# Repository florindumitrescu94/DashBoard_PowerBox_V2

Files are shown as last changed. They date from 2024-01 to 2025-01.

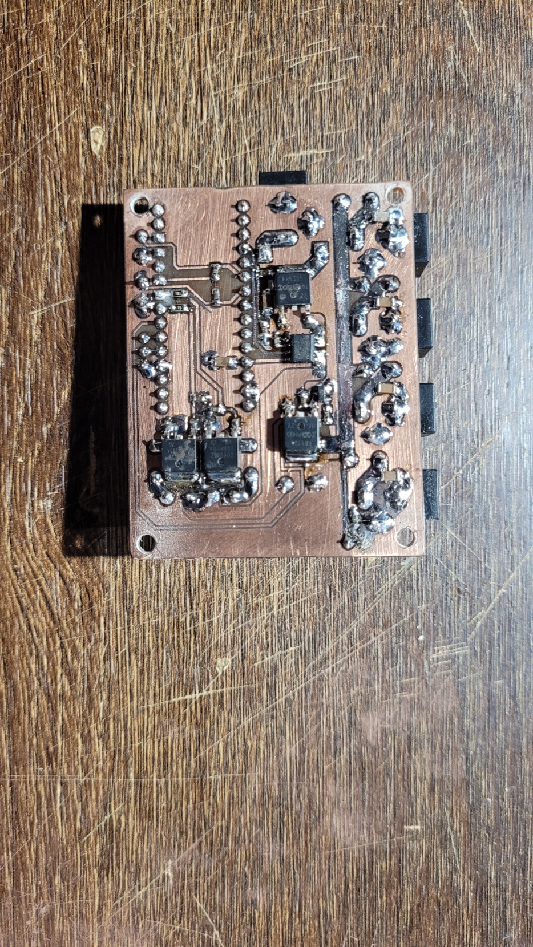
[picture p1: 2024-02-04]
DashBoard_PowerBox_V2_Documents/pcb_after_components_bottom.jpg

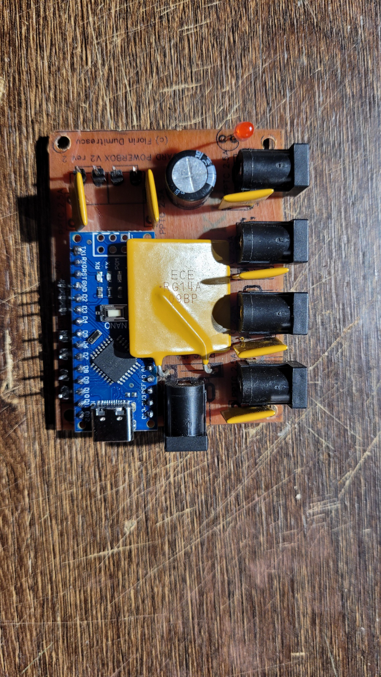
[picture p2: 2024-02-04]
DashBoard_PowerBox_V2_Documents/pcb_after_components_top.jpg

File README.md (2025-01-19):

# DashBoard PowerBoxV2
<p>Improved DIY powerbox based on Arduino Nano, with environmental sensors, power condition monitoring and dew heater power automation based on temperature probes</p>
<p>Please see <a href="https://github.com/florindumitrescu94/DashBoard_PowerBox_V2/wiki"> Wiki page </a> for more information.</p>
</br>
<p>To report any issues or request new features, please use the <a href=https://github.com/florindumitrescu94/DashBoard_PowerBox_V2/issues>Issues page</a></p>
</br>
<p>All feedback and suggestions are welcome! You can use the <a href=https://github.com/florindumitrescu94/DashBoard_PowerBox_V2/discussions> Discussions page</a> to share your ideas, ask questions or get help. </p>

</br>
</br>
</br>
</br>
</br>
<p>For direct contact, you can reach me at florin.dumitrescu94@gmail.com </p>
<p>Special thanks to wittinobi for making his driver code available! I have learned how an ASCOM driver works by analyzing his code.</p>

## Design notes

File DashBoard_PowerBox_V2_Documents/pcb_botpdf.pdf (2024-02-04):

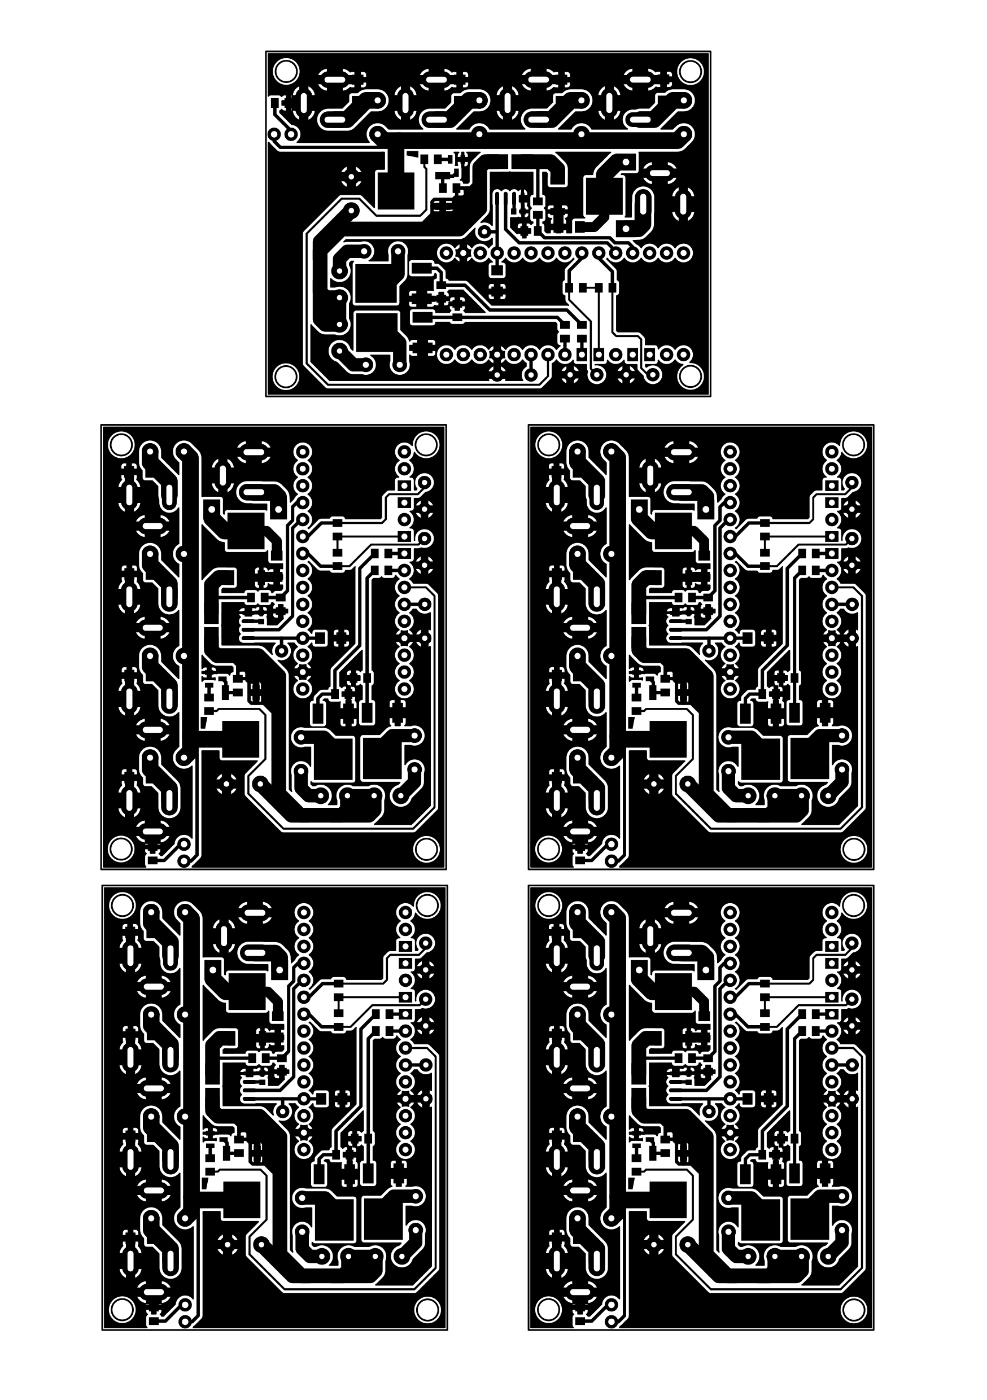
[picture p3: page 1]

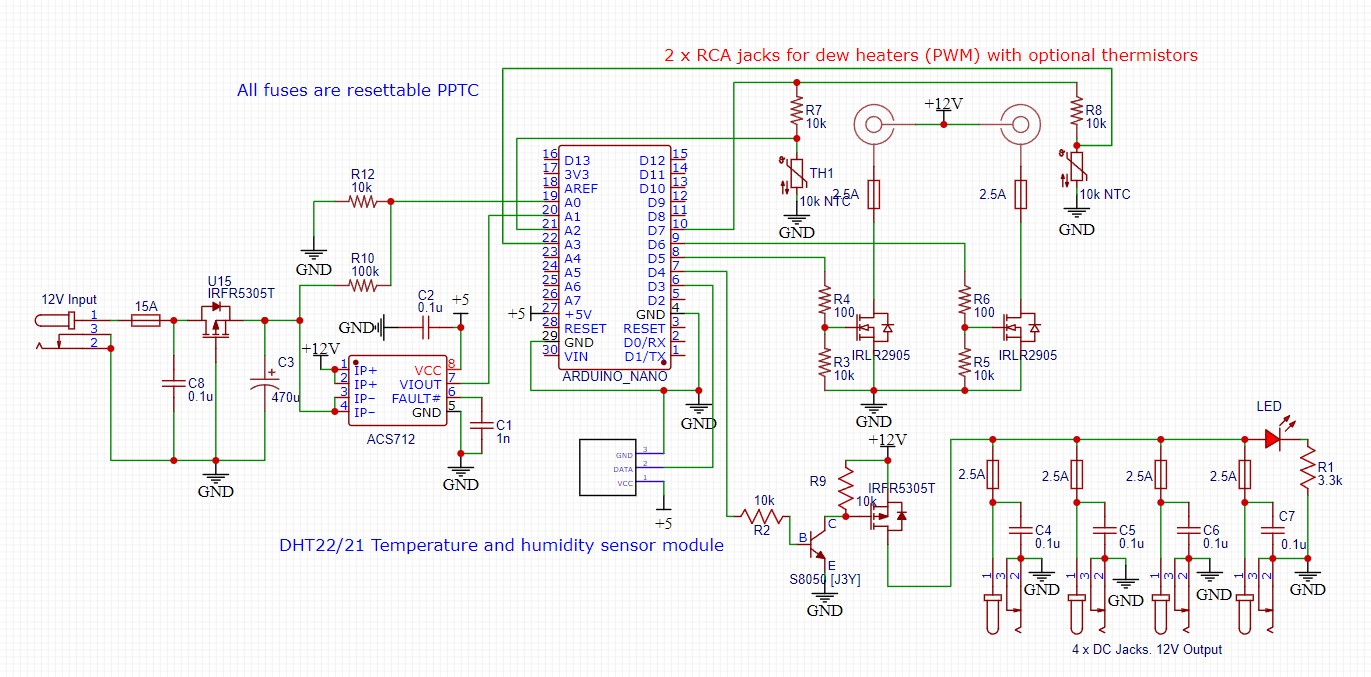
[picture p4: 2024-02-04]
DashBoard_PowerBox_V2_Documents/Schematic.jpg

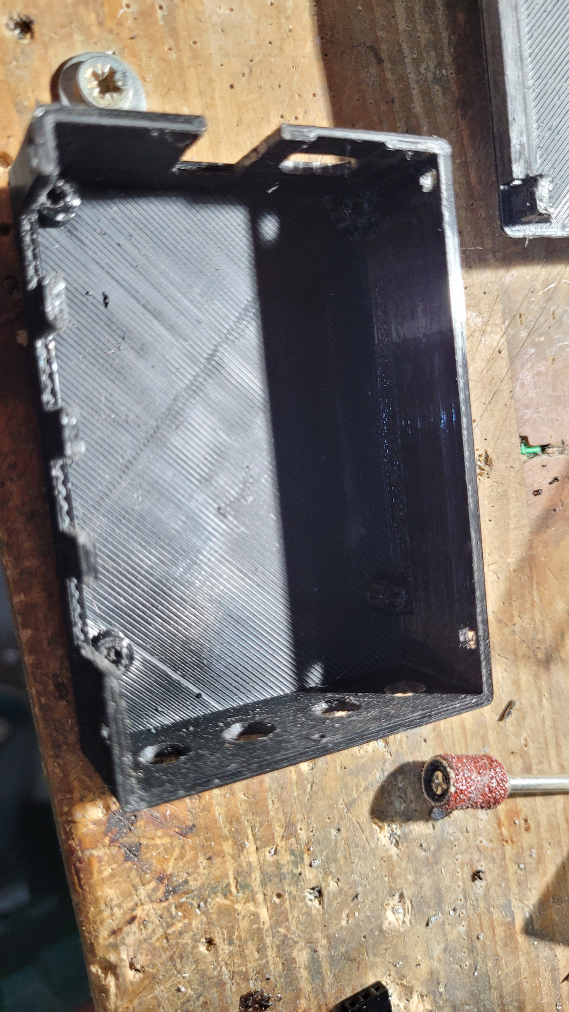
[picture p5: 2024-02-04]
DashBoard_PowerBox_V2_Documents/dashboard_inside_box.jpg

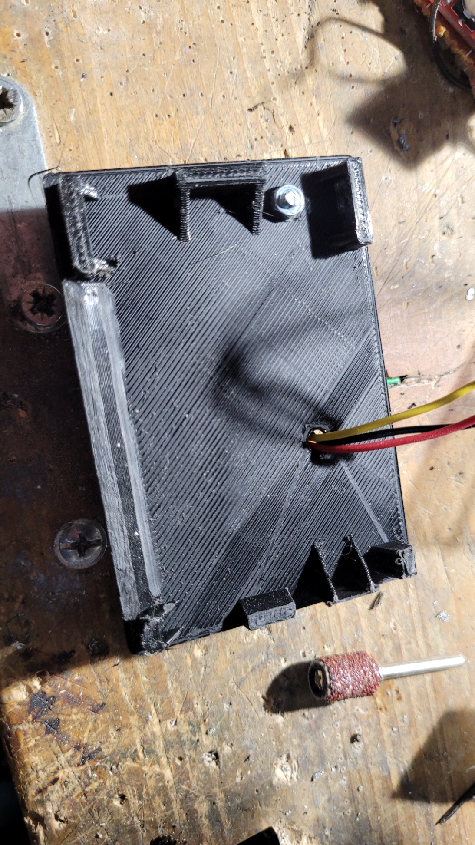
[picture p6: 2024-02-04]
DashBoard_PowerBox_V2_Documents/dashboard_inside_lid.jpg

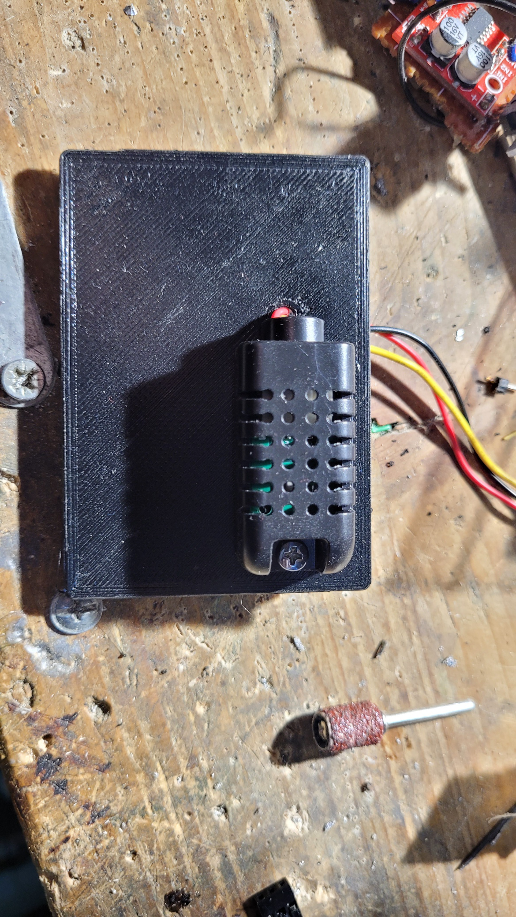
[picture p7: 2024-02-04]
DashBoard_PowerBox_V2_Documents/dashboard_lid_dhtsensor.jpg

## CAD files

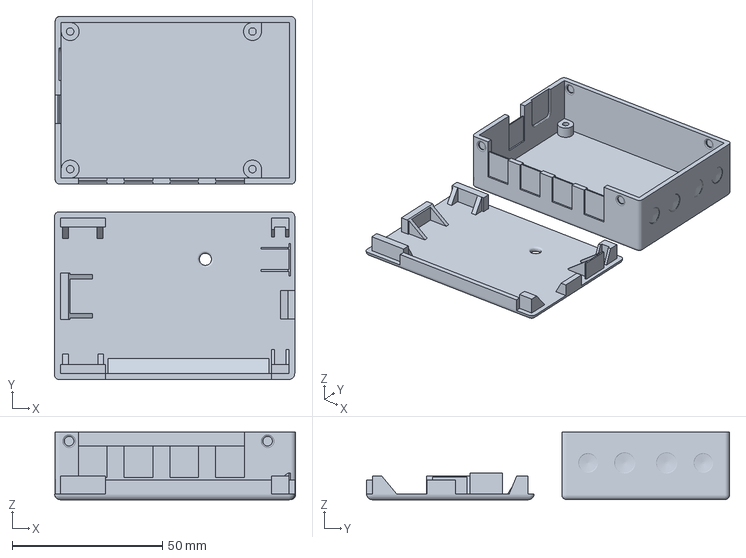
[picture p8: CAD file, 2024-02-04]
DashBoard_PowerBox_V2_Documents/CE3E3V2_DashBoard_PowerBox_V2 v2.3mf
80.2 x 120.8 x 22.5 mm

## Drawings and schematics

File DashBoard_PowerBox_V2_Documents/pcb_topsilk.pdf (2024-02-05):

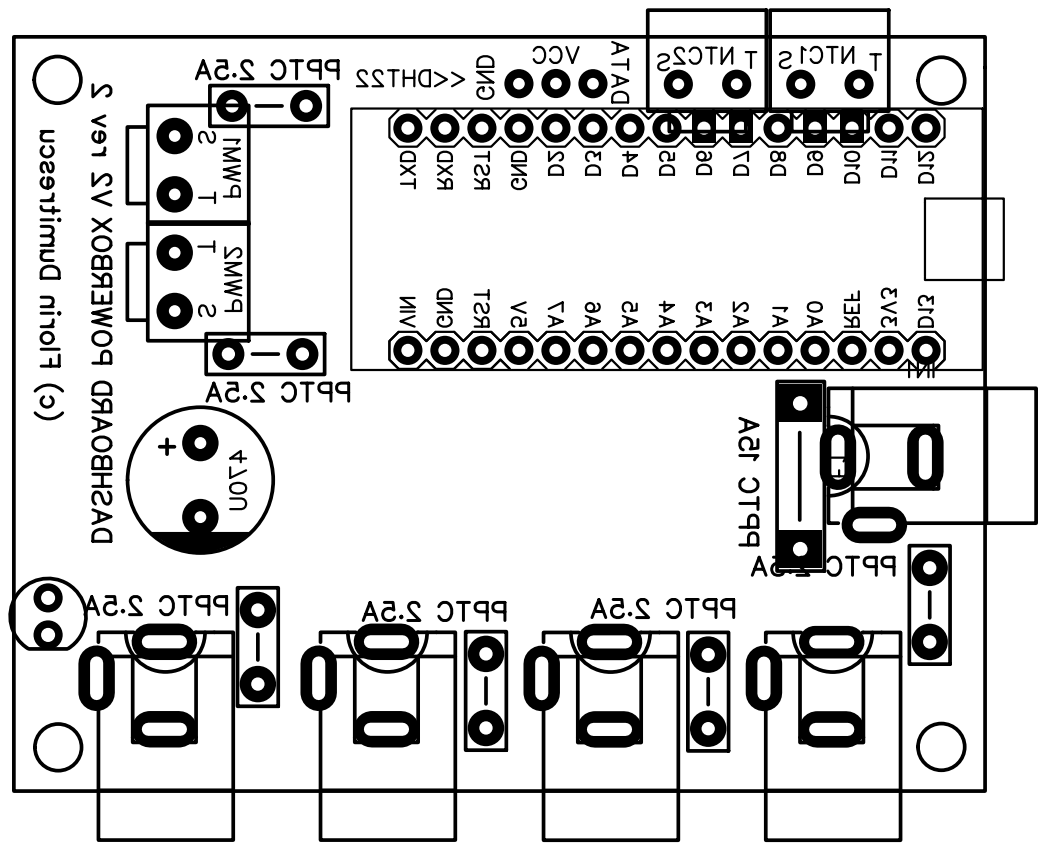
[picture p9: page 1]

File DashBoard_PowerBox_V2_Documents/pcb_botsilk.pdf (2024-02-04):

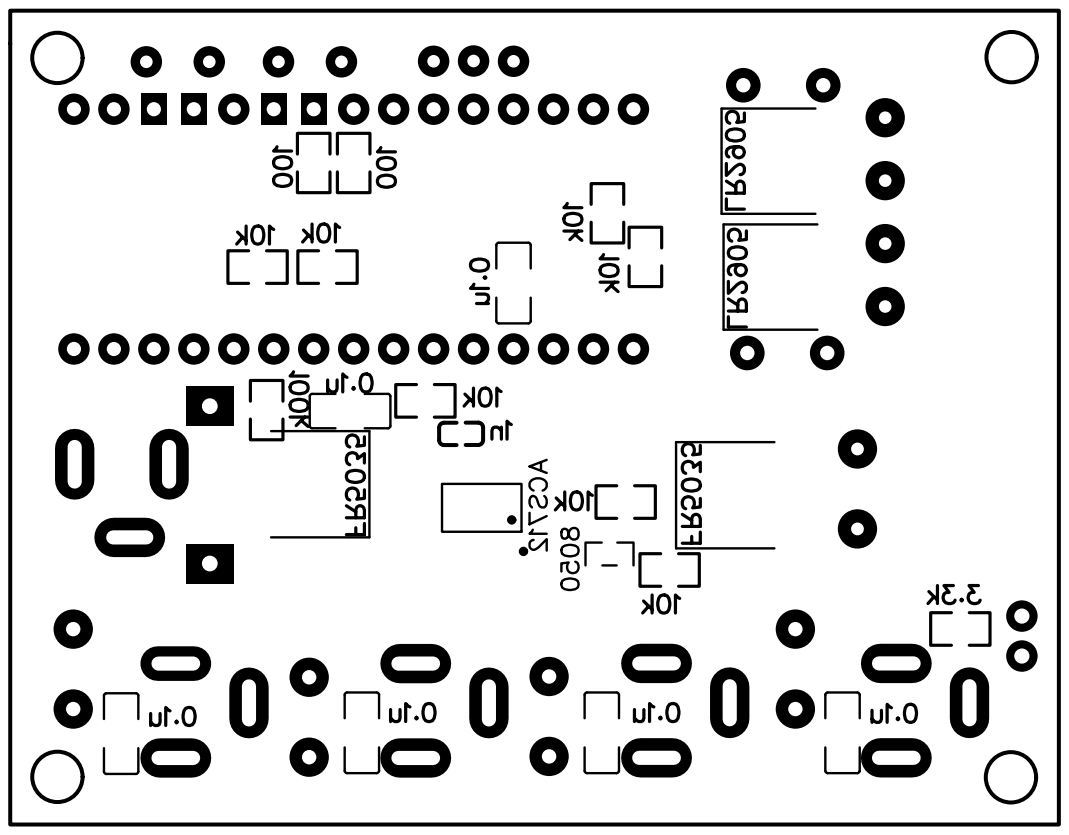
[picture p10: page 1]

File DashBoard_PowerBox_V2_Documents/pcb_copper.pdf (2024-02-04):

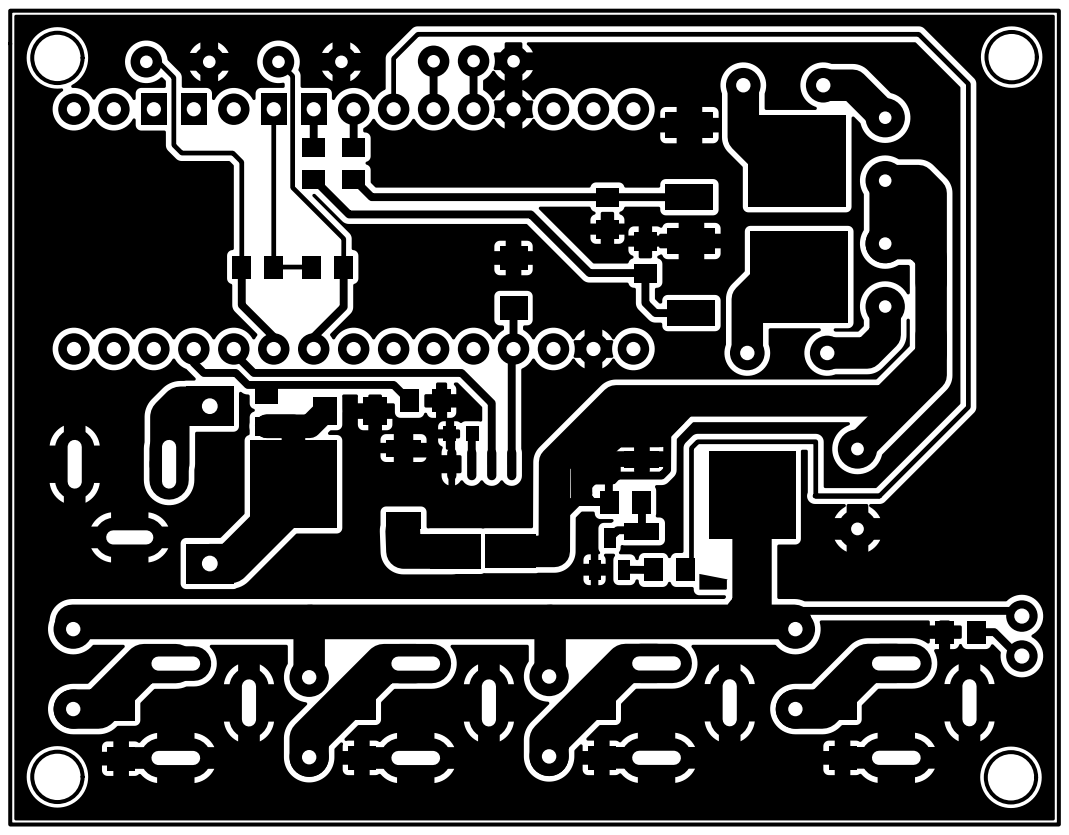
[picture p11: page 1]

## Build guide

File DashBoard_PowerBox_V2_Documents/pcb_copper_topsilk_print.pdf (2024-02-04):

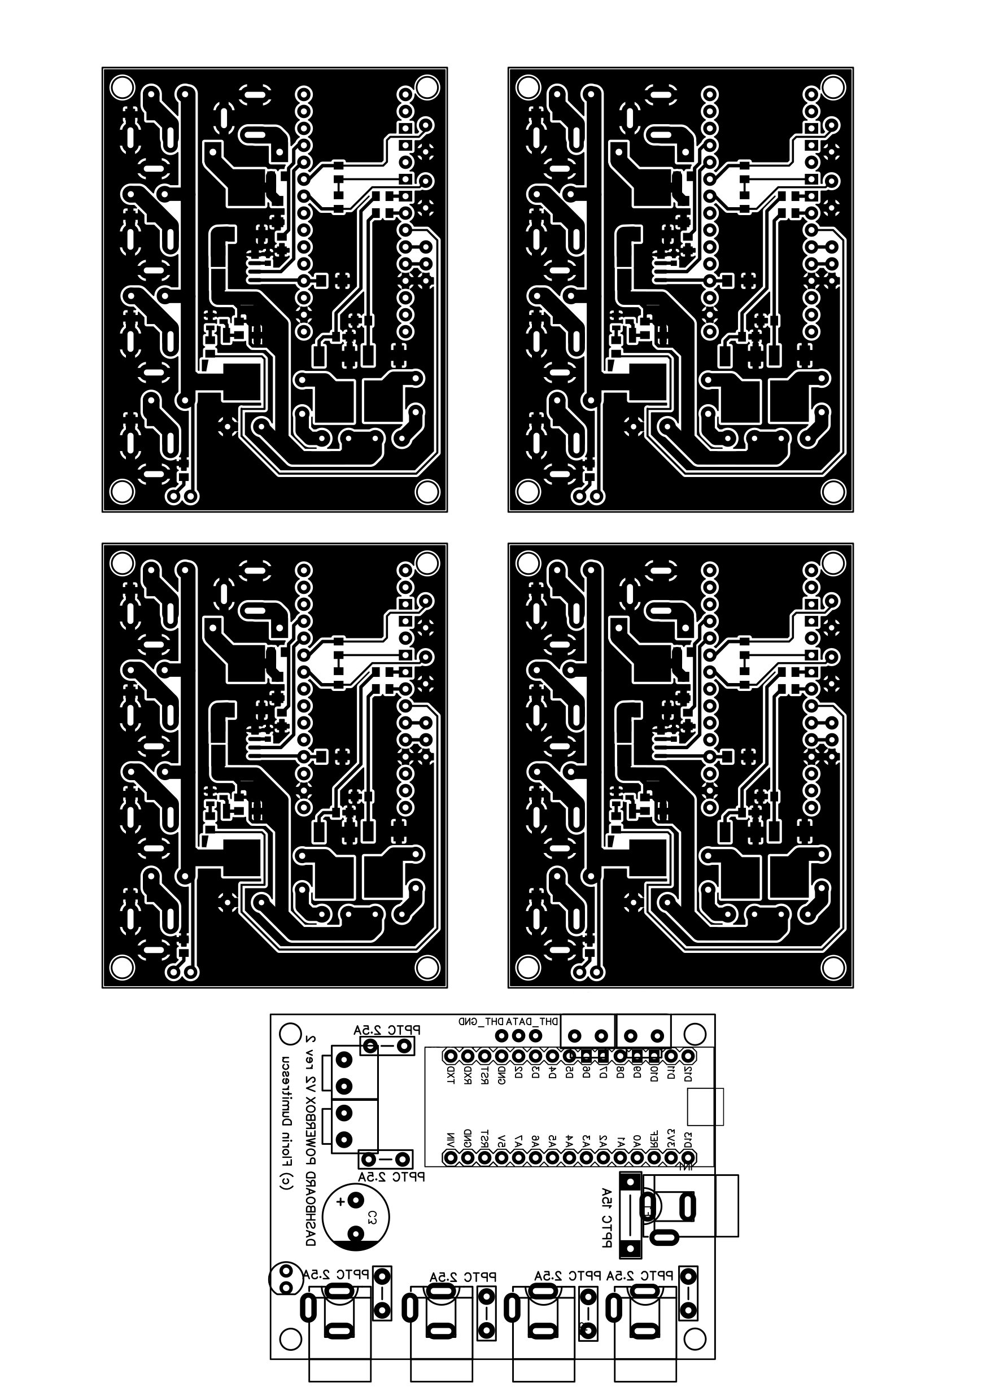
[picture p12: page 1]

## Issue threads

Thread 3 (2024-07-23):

No separators displayed

energiebrand, 2024-07-23:
I have the problem that under N.I.N.A. (ASCOM) unfortunately no separators are displayed in the measured values. For example, if the temperature is 23.45°C, then in N.I.N.A "2345" will be displayed. Could this be due to the ASCOM driver? Here in Germany (possibly all of Europe) a comma is expected as a separator, not a period. Is this where the problem lies?

florindumitrescu94, 2024-07-23:
Hello! It could be that.. I am in Europe too, but I've always been using US
settings on my computer, so I've never faced this issue.

Thing is, there is no setting in the ASCOM driver that I know of that sets
the decimal separator. Also, the values in the arduino also have a dot as a
decimal separator.

I tried changing my settings to use a comma as a decimal separator, but
NINA seems to be using a dot as a decimal separator, anyways, so I suspect
it is forcing the decimal separator to always be "." in its' code. When I
tried starting the powerbox driver with the Region settings set to Germany,
I got the same result as you (no separators).

I guess there is a way to avoid this issue by forcing the decimal separator
to always be "." in the driver, as well. I will add the necessary code to
the driver, but I am currently away on vacation and I'll be back beginning
of August. I'll let you know when I release the solution.

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

energiebrand, 2024-07-23:
Meanwhile I found the problem in the Windows settings. I had to change the settings from "," to ".". Hope that will have no negative influence on anything in N.I.N.A. :-)

florindumitrescu94, 2024-07-23:
Glad to hear it worked for you! Yeah, NINA seems to be happy with "." as decimal separator. I will include a fix for this in my driver to avoid this in the future. Thanks a bunch for raising this issue!

energiebrand, 2024-07-24:
Yes, it would be nice if the user will be able to select the separator in the ASCON-configuration window maybe. Changing it globally in WIN is not a good solution. Don't know if it will be possible. Maybe you should add  a hint in your description if someone runs into the trap.

Closed 2024-07-23.

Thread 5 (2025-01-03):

Ascom Driver Error

NJAJ63, 2025-01-03:
Hi florindumitrescu94

Installed the Ascom driver from the executable on https://github.com/florindumitrescu94/DashBoard_PowerBox_V2/releases/tag/v2.0.3
Driver installs successfully

Selecting DashBoard PowerBox V2 in NINA switches and setting to correct COM port and trying to connect to the switch

**Expected behavior**
Switch connecting and showing switch options

**Screenshots**
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

Trace:
11:48:49.440 Switch                    Starting driver initialisation
11:48:49.440 Switch                    ProgID: ASCOM.DashBoardPowerBoxV2.Switch, Description: DashBoard PowerBox V2
11:48:49.440 Switch                    Completed initialisation
11:48:49.441 Connected Set             Connecting to device
11:49:09.520 Connected Get             True
11:49:09.521 MaxSwitch                 4
11:49:09.521 CanWrite                  Calling method.
11:49:09.522 CanWrite                  True
11:49:09.522 GetSwitchName             Calling method.
11:49:09.525 GetSwitchName             DC Jacks
11:49:09.526 GetSwitchDescription      Calling method.
11:49:09.527 GetSwitchDescription      DC Jacks x4 12V
11:49:09.527 GetSwitchValue            Calling method.
11:49:09.533 GetSwitchValue            Threw an exception:
**_ASCOM.MethodNotImplementedException: Method GetSwitchValue is not implemented in this driver._**
   at ASCOM.DashBoardPowerBoxV2.Switch.SwitchHardware.GetSwitchValue(Int16 id)
   at ASCOM.DashBoardPowerBoxV2.Switch.Switch.GetSwitchValue(Int16 id)
11:49:09.539 GetSwitch                 Calling method.
11:49:14.612 GetSwitch                 Threw an exception:
System.Runtime.InteropServices.COMException (0x80040402): Timed out waiting for received data

**Desktop (please complete the following information):**
 - OS: [e.g. iOS] Windows 11
 - Browser [e.g. chrome, safari] Chrome/Edge
 - Version [e.g. 22]
 -
[ASCOM.DashBoardPowerBoxV2.Driver.1148.494390.txt](https://github.com/user-attachments/files/18299558/ASCOM.DashBoardPowerBoxV2.Driver.1148.494390.txt)

**Additional context**
Add any other context about the problem here.

NJAJ63, 2025-01-03:
Hi FLO

Just tried a fresh install on a different computer and all looks ok

Must be a remnant of 2.0.3 somewhere on the old computer

Thanks for you help

Nick

florindumitrescu94, 2025-01-03:
NJAJ63
Sorry for the mixup in the Wiki, I've corrected that now. Might want to think of a better way to do this than a fixed link in a wiki haha.
Please make sure to also upload the 2.0.5 Arduino code on your Arduino. It's not compatible with the 2.0.3 code.
I've also had trouble with installing and reinstalling the drivers on the same computer... I am not sure what's going on and what remnants are left from the install. I managed to trick my system into accepting a new driver by also deleting the entries in regedit. You might have some luck by checking the ASCOM Profile Explorer and see if you can find anything there.

Closed 2025-01-03.

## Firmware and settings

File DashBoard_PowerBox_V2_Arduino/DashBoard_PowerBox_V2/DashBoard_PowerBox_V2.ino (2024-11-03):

/* Written by: Florin Dumitrescu
 *  for ascom_powerbox_and_ambientconditions built with
 *  Arduino NANO V3
 *  January 2024
 *  DashBoard Arduino code
 */
//INCLUDE LIBRARIES

#include <DHTStable.h>;
DHTStable DHT;





//CODE VARIABLES
int DC_JACK_STATE = 1;
int PWM1_STATE = 0;
int PWM2_STATE = 0;
float NTC1_VALUE = 0;
int PWM_AUTO = 0;
float NTC2_VALUE = 0;
float TEMP = 0.0;
int HUM_REL = 0;
float HUM_ABS = 0.0;
float DEWPOINT = 0.0;
float DP_OFFSET = 2;
float VOLT = 0.00;
float VOLT_TEMP = 0.00;
int PIN_VALUE_A = 0;
int PIN_VALUE_V = 0;
float CURRENT_SAMPLE_SUM = 0.0;
int AVERAGE_COUNT = 0;
float AMP_AVERAGE[150];
float AVGAMP;
float AMP = 0.00;
float PWR = 0.00;
long int time1=0;
long int time2=0;
float timetotal_ntc=0;
double PWR_TOTAL_S=0.00;
float PWR_TOTAL=0.00;
float NTC_DELAY;
double ACS_resolution;

#define QUEUELENGTH         10             // number of commands that can be saved in the serial queue
#define MAXCOMMAND          42            // max length of a command
#define EOFSTR              '\n'
#define EOCOMMAND           '#'           // defines the end character of a command
#define SOCOMMAND           '>'           // defines the start character of a command
#define REFRESH             200           // read values every REFRESH milliseconds
#define PWMREFRESH          60000         // adjust PWM every 60 seconds
char* queue[QUEUELENGTH];
int queueHead = -1;
int queueCount = 0;
enum FSMStates { stateIdle, stateNtc, statePower, stateAutoPWM };
int idx = 0;                              // index into the command string
long int now;                             // now time in millis
long int last;                            // last time in millis
long int lastm;                           // last time we updated the dewheaters in millis
String line;                              // command buffer


//CONSTANTS  --- SET THESE TO YOUR MEASURED VALUES!
const int ACS_Variant = 20;
const int ntc_beta = 3380;
const int ntc_ohm  = 10000;
const int ref_ohm1 = 10080;
const int ref_ohm2 = 10000;

//PINS
const int DC_JACK = 4;
const int PWM1 = 5;
const int PWM2 = 6;
const int DHT22_VCC = 2;
const int DHT22_DATA = 3;
const int NTC_VCC = 7;
const int VM = A0;
const int AM = A1;
const int NTC1 = A2;
const int NTC2 = A3;


//-----------------------------------------------------------------------
// Utility functions
//-----------------------------------------------------------------------

char* pop() {
  --queueCount;
  return queue[queueHead--];
}


void push(char command[MAXCOMMAND]) {
  queueCount++;
  queueHead++;
  strncpy(queue[queueHead], command, MAXCOMMAND);
}


//ARDUINO INITIALIZATION
void setup()
{
    pinMode(DC_JACK, OUTPUT);
    pinMode(PWM1, OUTPUT);
    pinMode(PWM2, OUTPUT);
    pinMode(DHT22_DATA, INPUT);
    pinMode(DHT22_VCC, OUTPUT);
    pinMode(NTC_VCC, OUTPUT);
    pinMode(VM, INPUT);
    pinMode(AM, INPUT);
    pinMode(NTC1, INPUT);
    pinMode(NTC2, INPUT);

    digitalWrite(DC_JACK, LOW);
    digitalWrite(DHT22_VCC, HIGH);
    digitalWrite(PWM1, LOW);
    digitalWrite(PWM2, LOW);
    digitalWrite(NTC_VCC,LOW);
    
    for ( int i=0; i < QUEUELENGTH; i++)
      queue[i] = (char*)malloc(MAXCOMMAND);
    line.reserve(MAXCOMMAND);
    
    Serial.begin(9600);
    Serial.flush();

    switch (ACS_Variant){
      case 5: 
        ACS_resolution = 0.185;
        break;
      case 20: 
        ACS_resolution = 0.100;
        break;
      case 30:
        ACS_resolution = 0.066;
        break;
    }
    // initialize our delays
    now = millis();
    last = now;
    lastm = now;
}

void clearSerialPort() {
  while ( Serial.available() )
    Serial.read();
}

// SerialEvent occurs whenever new data comes in the serial RX.
// you should really consider a start of command character.
void serialEvent() {

  // '#' ends the command, do not store these in the command buffer
  // read the command until the terminating # character
  char buf[MAXCOMMAND];
  while ( Serial.available() )
  {
    char inChar = Serial.read();
    switch ( inChar )
    {
      case '>':     // soc, reinit line
        // memset(line, 0, MAXCOMMAND);
        line = "";
        idx = 0;
        break;
      case '#':     // eoc
        line.toCharArray(buf, MAXCOMMAND);
        idx = 0;
        push(buf);
        break;
      default:      // anything else
        if ( idx < MAXCOMMAND - 1) {
          line += inChar;
        }
        break;
    }
  }
}


void processSerialCommand() {
  // this should never happen
  if ( queueCount == 0 )
    return;

  String cmd = String(pop());
  //if (cmd == "GETSTATUSDCJACK") {
    //  Serial.print(DC_JACK_STATE);
      //Serial.println("#");
  //}
  if (cmd == "SETSTATUSDCJACK_OFF") SET_DC_JACK(0);
  else if (cmd == "SETSTATUSDCJACK_ON") SET_DC_JACK(1);
  else if (cmd == "SETAUTOPWM_ON") {
      PWM_AUTO = 1;
      //Serial.print(PWM_AUTO);
      //Serial.println("#");
  }
  else if (cmd == "SETAUTOPWM_OFF") {
    PWM_AUTO = 0;
    //Serial.print(PWM_AUTO);
    //Serial.println("#");
  }
  //else if (cmd == "GETAUTOPWM") {
    //Serial.print(PWM_AUTO);
    //Serial.println("#");
  //}
  
  else if (cmd.substring(0,13) == "SETSTATUSPWM1") SET_PWM_POWER(1,cmd.substring((cmd.indexOf('_')+1),(cmd.indexOf('_')+4)).toInt()); 
  else if (cmd.substring(0,13) == "SETSTATUSPWM2") SET_PWM_POWER(2,cmd.substring((cmd.indexOf('_')+1),(cmd.indexOf('_')+4)).toInt());
  else if (cmd == "REFRESHDATA")
  {
    Serial.print(PWM1_STATE);
    Serial.print(":");
    Serial.print(PWM2_STATE);
    Serial.print(":");
    Serial.print(TEMP);
    Serial.print(":");
    Serial.print(HUM_REL);
    Serial.print(":");
    Serial.print(DEWPOINT);
    Serial.print(":");
    Serial.print(VOLT);
    Serial.print(":");
    Serial.print(AMP);
    Serial.print(":");
    Serial.print(PWR);
    Serial.print(":");
    Serial.print(PWR_TOTAL);
    Serial.print(":");
    Serial.print(NTC1_VALUE);
    Serial.print(":");
    Serial.print(NTC2_VALUE);
    Serial.print(":");
    Serial.print(DC_JACK_STATE);
    Serial.print(":");
    Serial.print(PWM_AUTO);
    Serial.print("#");
  }
}


//LOOP TO READ SERIAL COMMANDS
void loop()
{
  GET_POWER(); //needs to run constantly for correct calculations
  static byte FSMState = stateIdle;

  if ( queueCount >= 1 ) {               // check for serial command
    processSerialCommand();
  }

  switch (FSMState) {
    case stateIdle:
      // wait REFRESH milliseconds between Read cycles
      now = millis();
      if ( now > last + REFRESH )
        FSMState = stateNtc;
      else
        FSMState = stateIdle;
      break;
    case stateNtc:
      GET_NTC();
      now = millis();
      last = now;
      FSMState = statePower;
      break;
    case statePower:
      GET_AMBIENT();
      now = millis();
      FSMState = stateAutoPWM;
      last = now;
      break;
    case stateAutoPWM:
      now = millis();
      if ( now > lastm + PWMREFRESH ) {
        RUN_AUTO_PWM();
        lastm = now;
      }
      last = now;
      FSMState = stateIdle;
      break;
  }
} 
// END loop


//SET/GET FUNCTIONS


//SET DC JACK STATE
void SET_DC_JACK(int state){
     if (state==0) digitalWrite(DC_JACK, LOW);
     else if (state==1) digitalWrite(DC_JACK, HIGH);
     DC_JACK_STATE = state;
     //Serial.print(DC_JACK_STATE);
     //Serial.println("#");
}
//END SET DC JACK STATE

//SET PWM POWER
void SET_PWM_POWER(int pwmno,int state) {
    int pwm_pin = (state*255)/100;
    if (pwmno == 1)
    {
    analogWrite(PWM1, pwm_pin);
    PWM1_STATE = state;
    //Serial.print(PWM1_STATE);
    //Serial.println("#");
    }
    else if (pwmno == 2)
    {
    analogWrite(PWM2, pwm_pin);
    PWM2_STATE = state;
    //Serial.print(PWM2_STATE);
    //Serial.println("#");
    }
}
//END SET PWM POWER

// RUN PWM AUTO 
void RUN_AUTO_PWM() {
   if (HUM_REL>50) DP_OFFSET = ((HUM_REL/10)-5);
   else if (HUM_REL<50) DP_OFFSET = 0;
   if(PWM_AUTO == 1) // PWM1 AUTO
   {
     if (NTC1_VALUE > -40) {
     if (NTC1_VALUE - (DEWPOINT + DP_OFFSET) < 2 && PWM1_STATE < 100)
     {
       PWM1_STATE = PWM1_STATE + 5;
       PWM1_STATE = CORRECT_PWM(PWM1_STATE);
        SET_PWM_VALUE(1,PWM1_STATE);
      }
     if (NTC1_VALUE - (DEWPOINT + DP_OFFSET) > 4 && PWM1_STATE > 0)
      {
        PWM1_STATE = PWM1_STATE - 5;
        PWM1_STATE = CORRECT_PWM(PWM1_STATE);
        SET_PWM_VALUE(1,PWM1_STATE);
      }
     }
     if (NTC2_VALUE > -40) {
     if (NTC2_VALUE - (DEWPOINT + DP_OFFSET) < 2 && PWM2_STATE<100)
     {
       PWM2_STATE = PWM2_STATE + 5;
        PWM2_STATE = CORRECT_PWM(PWM2_STATE);
        SET_PWM_VALUE(2,PWM2_STATE);
     }
     if (NTC2_VALUE - (DEWPOINT + DP_OFFSET) > 4 && PWM2_STATE>0)
     {
       PWM2_STATE = PWM2_STATE - 5;
       PWM2_STATE = CORRECT_PWM(PWM2_STATE);
       SET_PWM_VALUE(2,PWM2_STATE);
     }
     }
   }
   else if (PWM_AUTO == 0) timetotal_ntc = 0;
}
//END SET AUTO PWM POWER

//GET NTC TEMP
void GET_NTC(){
   digitalWrite(NTC_VCC,HIGH);
   int ntc1_read_sum = 0;
   int ntc2_read_sum = 0;
   float avg1_read = 0;
   float avg2_read = 0;
   for (int i=0;i<40;i++)
   {
    ntc1_read_sum +=analogRead(NTC1);
    delay(1);
    ntc2_read_sum +=analogRead(NTC2);
   }
   avg1_read = ntc1_read_sum/40;
   avg2_read = ntc2_read_sum/40;
   digitalWrite(NTC_VCC,LOW);
   avg1_read = (1023 / avg1_read)-1;
   avg2_read = (1023 / avg2_read)-1;
   avg1_read = ntc_ohm / avg1_read;
   avg2_read = ntc_ohm / avg2_read;
   float temp1_ntc = avg1_read / ref_ohm1 ;
   float temp2_ntc = avg2_read/ ref_ohm2;
   temp1_ntc=log(temp1_ntc);
   temp1_ntc /= ntc_beta;
   temp1_ntc +=1.0/(25 + 273.15);
   temp1_ntc = (1.0/temp1_ntc) - 273.15; 
   if (isnan(temp1_ntc)) temp1_ntc = -40;
   temp2_ntc=log(temp2_ntc);
   temp2_ntc /= ntc_beta;
   temp2_ntc +=1.0/(25 + 273.15);
   temp2_ntc = (1.0/temp2_ntc) - 273.15; 
   if (isnan(temp2_ntc))temp2_ntc = -40;
   NTC1_VALUE=temp1_ntc - 1;
   NTC2_VALUE=temp2_ntc - 1;
}
// END GET NTC TEMP

//MEASURE AND CALCULATE POWER USAGE
  void GET_POWER() {
    time1=millis();
    if (AVERAGE_COUNT == 150) AVERAGE_COUNT = 0;
    float VOLTAGE_SAMPLE_SUM=0;
    for (int v=0;v<150;v++) 
    {
      PIN_VALUE_V =  analogRead(VM);
      VOLTAGE_SAMPLE_SUM +=PIN_VALUE_V;     
    }
    VOLTAGE_SAMPLE_SUM /=150;
    VOLT_TEMP = (VOLTAGE_SAMPLE_SUM * 5.0) / 1024.0;   
    VOLT = VOLT_TEMP / 0.0982;        
    if (VOLT < 0.1) VOLT=0.0;    
    CURRENT_SAMPLE_SUM=0;
    for (int i=0;i<150;i++)
    {
      PIN_VALUE_A= analogRead(AM);
      CURRENT_SAMPLE_SUM = CURRENT_SAMPLE_SUM + PIN_VALUE_A;
    }
    AMP_AVERAGE[AVERAGE_COUNT] = (2.494 - ((CURRENT_SAMPLE_SUM/150)*(5.0/1024.0))) / ACS_resolution;
    AVGAMP=0;
    for (int c=0;c<150;c++) AVGAMP += AMP_AVERAGE[c];
    AMP = AVGAMP/150;
    if (AMP< 0.01) AMP=0.0;
    PWR_TOTAL_S = PWR_TOTAL_S + ((((PWR+(VOLT*AMP))/2)*(time1-time2))/1000); // total power in W*s between cycles
    PWR = VOLT * AMP;
    AVERAGE_COUNT = AVERAGE_COUNT + 1;
    time2=millis();
    PWR_TOTAL_S = PWR_TOTAL_S + ((PWR*(time2-time1))/1000); // total power in W*s
    PWR_TOTAL = PWR_TOTAL_S/3600;  // Total power used in W*h                                   
}
//END GET POWER USAGE

//GET AMBIENT CONDITIONS
  void GET_AMBIENT() {
  int PIN_VALUE_T = DHT.read22(DHT22_DATA);
   HUM_REL = DHT.getHumidity();
   TEMP = DHT.getTemperature();
   DEWPOINT  = (TEMP - (100 - HUM_REL) / 5);
 }
 //CORRECT PWM VALUE
 void SET_PWM_VALUE(int pwmno, int value){
  value = CORRECT_PWM(value);
  int pwm_pin = (value*255)/100;
  if (pwmno == 1) analogWrite (PWM1, pwm_pin);
  if (pwmno == 2) analogWrite (PWM2, pwm_pin);
 }
 int CORRECT_PWM(int state){
 if (state > 100) return 100;
 if (state < 0) return 0;
 else return state;
}
 

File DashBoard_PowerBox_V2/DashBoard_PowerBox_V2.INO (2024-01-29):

/* Written by: Florin Dumitrescu
 *  for ascom_powerbox_and_ambientconditions built with
 *  Arduino NANO V3
 *  January 2024
 *  DashBoard Arduino code
 */
//INCLUDE LIBRARIES

#include <DHTStable.h>;
DHTStable DHT;



//DECLARE VARIABLES
int DC_JACK_STATE = 0;
int PWM1_STATE = 0;
int PWM2_STATE = 0;
float NTC1_VALUE = 0;
int PWM1_AUTO = 0;
float NTC2_VALUE = 0;
int PWM2_AUTO = 0;
float TEMP = 0.0;
int HUM_REL = 0;
float HUM_ABS = 0.0;
float DEWPOINT = 0.0;
float VOLT = 0.00;
float VOLT_TEMP = 0.00;
int PIN_VALUE_A = 0;
int PIN_VALUE_V = 0;
float CURRENT_SAMPLE_SUM = 0.0;
int AVERAGE_COUNT = 0;
float AMP_AVERAGE[150];
float AVGAMP;
float AMP = 0.00;
float PWR = 0.00;
long int time1=0;
long int time2=0;
float timetotal_ntc1=0;
float timetotal_ntc2=0;
float PWR_TOTAL=0.00;

const int DC_JACK = 4;
const int PWM1 = 5;
const int PWM2 = 6;
const int DHT22_VCC = 7;
const int DHT22_DATA = 8;
const int DHT22_GND = 9;
const int NTC_VCC = 12;
const int VM = A0;
const int AM = A1;
const int NTC1 = A2;
const int NTC2 = A3;
//ARDUINO INITIALIZATION
void setup()
{
    pinMode(DC_JACK, OUTPUT);
    pinMode(PWM1, OUTPUT);
    pinMode(PWM2, OUTPUT);
    pinMode(DHT22_DATA, INPUT);
    pinMode(NTC_VCC, OUTPUT);
    pinMode(VM, INPUT);
    pinMode(AM, INPUT);
    pinMode(NTC1, INPUT);
    pinMode(NTC2, INPUT);

    digitalWrite(DC_JACK, LOW);
    digitalWrite(PWM1, LOW);
    digitalWrite(PWM2, LOW);
    digitalWrite(NTC_VCC,LOW);
    Serial.begin(9600);
    Serial.flush();
}

//LOOP TO READ SERIAL COMMANDS
void loop()
{
  int indexofpwm1=0;
  int indexofpwm2=0;
  String valueofpwm1="";
  String valueofpwm2="";
  if (PWM1_AUTO == 1){ SET_AUTO_PWM1(); }
  if (PWM2_AUTO == 1){ SET_AUTO_PWM2(); }
  GET_POWER();
    String cmd;

    if (Serial.available() > 0) {
        cmd = Serial.readStringUntil('#');
        if (cmd == "GETSTATUSDCJACK") 
        {
            Serial.print(DC_JACK_STATE);
            Serial.println("#");
        }
        else if (cmd == "SETSTATUSDCJACK_OFF") SET_DC_JACK(0);
        else if (cmd == "SETSTATUSDCJACK_ON") SET_DC_JACK(1);
        else if (cmd == "GETSTATUSPWM1") 
        {
            Serial.print(PWM1_STATE);
            Serial.println("#");
        }
        else if (cmd == "GETAUTOPWM1")
        {
          Serial.print(PWM1_AUTO);
          Serial.println("#");
        }
        else if (cmd == "SETAUTOPWM1_ON") {
          PWM1_AUTO = 1;
          Serial.print(PWM1_AUTO);
          Serial.println("#");
        }
        else if (cmd == "SETAUTOPWM1_OFF") {
          PWM1_AUTO = 0;
          Serial.print(PWM1_AUTO);
          Serial.println("#");
        }
        else if (cmd == "GETNTC1TEMP"){
          GET_NTC1();
          Serial.print(NTC1_VALUE);
          Serial.println("#");
        }
        else if (cmd == "GETNTC2TEMP"){
          GET_NTC2();
          Serial.print(NTC2_VALUE);
          Serial.println("#");
        }
        else if (cmd.substring(0,13) == "SETSTATUSPWM1") PWM1_POWER(cmd.substring((cmd.indexOf('_')+1),(cmd.indexOf('_')+4)).toInt()); 
        else if (cmd == "GETSTATUSPWM2") 
        {
            Serial.print(PWM2_STATE);
            Serial.println("#");
        }
        else if (cmd == "GETAUTOPWM2")
        {
          Serial.print(PWM2_AUTO);
          Serial.println("#");
        }
        else if (cmd == "SETAUTOPWM2_ON") {
          PWM2_AUTO = 1;
          Serial.print(PWM2_AUTO);
          Serial.println("#");
        }
        else if (cmd == "SETAUTOPWM2_OFF"){
          PWM2_AUTO = 0;
          Serial.print(PWM2_AUTO);
          Serial.println("#");
        }
        else if (cmd.substring(0,13) == "SETSTATUSPWM2") PWM2_POWER(cmd.substring((cmd.indexOf('_')+1),(cmd.indexOf('_')+4)).toInt());
        else if (cmd == "GETTEMPERATURE")
        { 
           GET_AMBIENT();
           Serial.print(TEMP);
           Serial.println("#");
        }
        else if (cmd == "GETHUMIDITY")
        {
           Serial.print(HUM_REL);
           Serial.println("#");
        }
        else if (cmd == "GETDEWPOINT")
        {
           Serial.print(DEWPOINT);
           Serial.println("#");
        }
        else if (cmd == "GETVOLTAGE")
        {
           Serial.print(VOLT);
           Serial.println("#");
        }
        else if (cmd == "GETCURRENT")
        { 
           Serial.print(AMP);
           Serial.println("#");
        }
        else if (cmd == "GETPOWER") 
        {
           Serial.print(PWR);
           Serial.println("#");
        }
        else if (cmd == "GETUSAGE")
        {
           Serial.print(PWR_TOTAL);
           Serial.println("#");
        }
//        else if (cmd =="GETALL") // USE FOR DEBUGGING 
//        {
//          Serial.print("DC Jacks state: ");
//          Serial.print(DC_JACK_STATE);
//          Serial.print(", PWM1 level :");
//          Serial.print(PWM1_STATE);
//          Serial.print(", PMW1 Auto :");
//          Serial.print(PWM1_AUTO);
//          Serial.print(", PWM2 level :");
//          Serial.print(PWM2_STATE);
//          Serial.print(", PWM2 Auto :");
//          Serial.print(PWM2_AUTO);
//          Serial.print(", NTC1 Temperature: ");
//          Serial.print(NTC1_VALUE);
//          Serial.print(", NTC2 Temperature: ");
//          Serial.print(NTC2_VALUE);
//          Serial.println();
//          Serial.print(", Ambiental temperature: ");
//          Serial.print(TEMP);
//          Serial.print(", Relative humidity: ");
//          Serial.print(HUM_REL);
//          Serial.print(", Dew point: ");
//          Serial.print(DEWPOINT);
//          Serial.print(", Voltage: ");
//          Serial.println();
//          Serial.print(VOLT);
//          Serial.print(", Current: ");
//          Serial.print(AMP);
//          Serial.print(", Power: ");
//          Serial.print(PWR);
//          Serial.print(", Total power used: ");
//          Serial.print(PWR_TOTAL);
//          Serial.println();
//          
//        }
    }
   //    Serial.println(timetotal_ntc2);
     //  Serial.println(timetotal_ntc1);
    
//    Serial.print(PIN_VALUE_V);
//    Serial.print(" - ");
//    Serial.print(VOLT);
//    Serial.print(" - ");
//    Serial.print(CURRENT_AVG);
//    Serial.print(" - ");
//    Serial.print(CURRENT_MID);
//    Serial.print(" - ");
//    Serial.print(CURRENT_TOTAL);
//    Serial.print(" = ");
//  Serial.print(AMP);
//    Serial.println();
} 

// END READ SERIAL COMMANDS


//SET/GET FUNCTIONS


//SET DC JACK STATE
void SET_DC_JACK(int state){
     if (state==0) digitalWrite(DC_JACK, LOW);
     else if (state==1) digitalWrite(DC_JACK, HIGH);
     DC_JACK_STATE = state;
     Serial.print(DC_JACK_STATE);
     Serial.println("#");
}
//END SET DC JACK STATE


//SET PWM1 POWER
  //PWM1_POWER
void PWM1_POWER(int state) {
    int pwm_pin = (state*255)/100;
    analogWrite(PWM1, pwm_pin);
    PWM1_STATE = state;
    Serial.print(PWM1_STATE);
    Serial.println("#");
}
//END SET PWM1 POWER
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

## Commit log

2024-01-29 Added arduino code file
2024-01-29 Created project for Arduino code
2024-01-29 Corrected Arduino project
2024-01-29 Arduino code optimization
2024-01-30 Arduino code - integrated pwm automation based on ntc, dew point and humidity. Driver - added pwm automation toggle, added checkbox to declare if ntc sensors are connected to show automation toggle
2024-02-04 started documentation. Images and pcb files added
    [CE3E3V2_DashBoard_PowerBox_V2 v2.3mf]
2024-02-05 changed arduino code for current and voltage
2024-02-05 updated top silkscreen
2024-02-06 added constants for voltage dividers values and acs variant
2024-02-06 updated total power calculation code
2024-02-07 reverted to number instead of formula for voltage divider ratio due to limitation in arduino fp. Added 150 sample gathering for voltage measurement
    [DashBoard_PowerBox_V2.ino]
2024-02-13 Update DashBoard_PowerBox_V2.ino
    updated pwr_total formula to include/estimate power consumption between get_power() cycles.
2024-02-23 Update DashBoard_PowerBox_V2.ino
    updated calculation of power
2024-03-11 Added command queue and FSM
    Queue support:
    the loop() function no longer blocks to get a full command: characters are read as soon as they arrive in the Serial ports through the serialEvent Method. the characters are asynchronously accumulated until a full command is received, at which point it is pushed onto a queue. The loop() function now only processes commands when there is a or a set of complete commands in the queue.
    FSM support:
    previously at each loop() all processing was executed which led to performance issues in addition to the blocking nature of command processing. Now loop is idle most of the time. Every 200ms temperature data is read. at the next loop() Power data is read, at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
    [DashBoard_PowerBox_V2.ino]
2024-03-11 removed timetotal_ntc for pwm set delay
    removed timetotal_ntc for pwm delay since it has been implemented in PWMREFRESH
    added set dp_offset to 0 if hum_rel < 50
2024-03-12 Driver update 2.0.5
    Updated driver to include NTC1 and NTC2 temperature readings in Gauges.
    Redesigned variable values update to work with a single serial string that gets split into an array.
    Removed writing each value to profile, as it was not useful
    Removed waiting for response from "Set" functions. The driver sometimes hangs when waiting for responses, but the values get updated on the hardware. (Will work to reenable responses).
    Updated arduino code to reflect single string values update.
    Included '>' as start of command pointer.
    [DashBoard_PowerBox_V2.ino]
2025-01-19 Update README.md
    Removed link for (obsolete) current version
